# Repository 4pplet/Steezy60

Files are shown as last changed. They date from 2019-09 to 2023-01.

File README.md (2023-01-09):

# Steezy60

Steezy60 is a 60% PCB in two versions: one for SMK gen 2 switches one for ALPS-compatible switches. Compatible with standard tray-mount cases.

## Some features:
- Extensive layout support for use with vintage keycap sets
- QMK
- Simple VIA support (just common layout options)
- USB C
- RGB underglow
- Cherry PCB-stab support for most layout options
- USB horizontal placement is classic GH60, same as GH60, plain60, voyager60 etc.
- JST-connector for daughter board (two different positions, one for bakeneko, one for cases compatible with wilba PCB.)

### SMK:
- Support for MX-mount switch on 6.25u and 7u spacebar position, this to enable use of silenced MX-switch on large spacebars. (no onion chopping spacebar sound)
- Support for some of the weird Alps switch positions for compatibility with SMK Alps mount switches and classic Alps keysets (not for cherry stem SMK switches).

## Availability:
As an option to DIY, I'll try and keep these available for purchase here: https://4pplet.com/ For DIY, the production files are avaliable in releases.

## Altium view of ALPS PCB
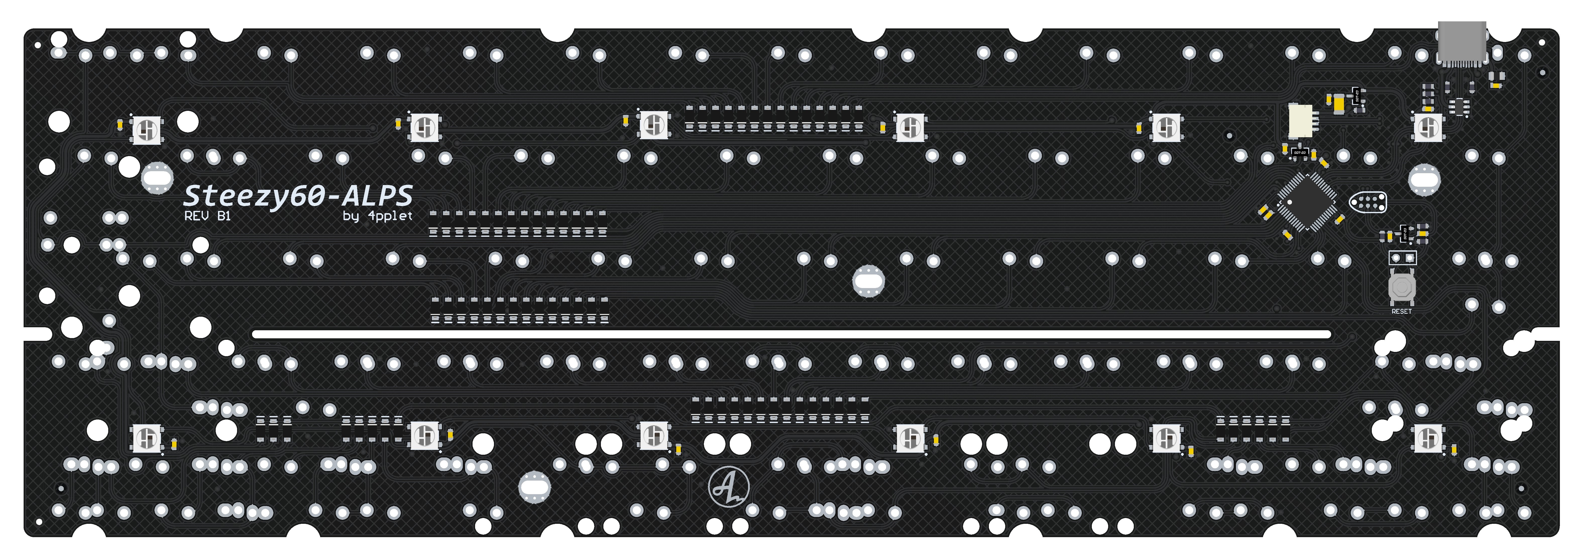
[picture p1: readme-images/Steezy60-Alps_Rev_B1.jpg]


## Altium view of SMK PCB
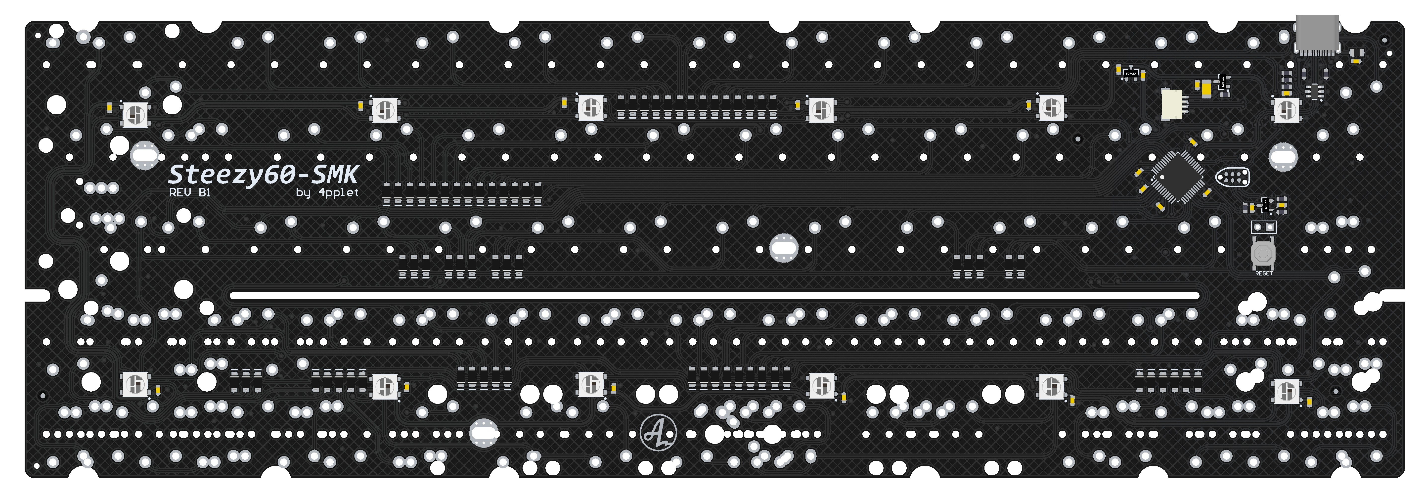
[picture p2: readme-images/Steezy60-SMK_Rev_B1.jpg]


## Layout support:
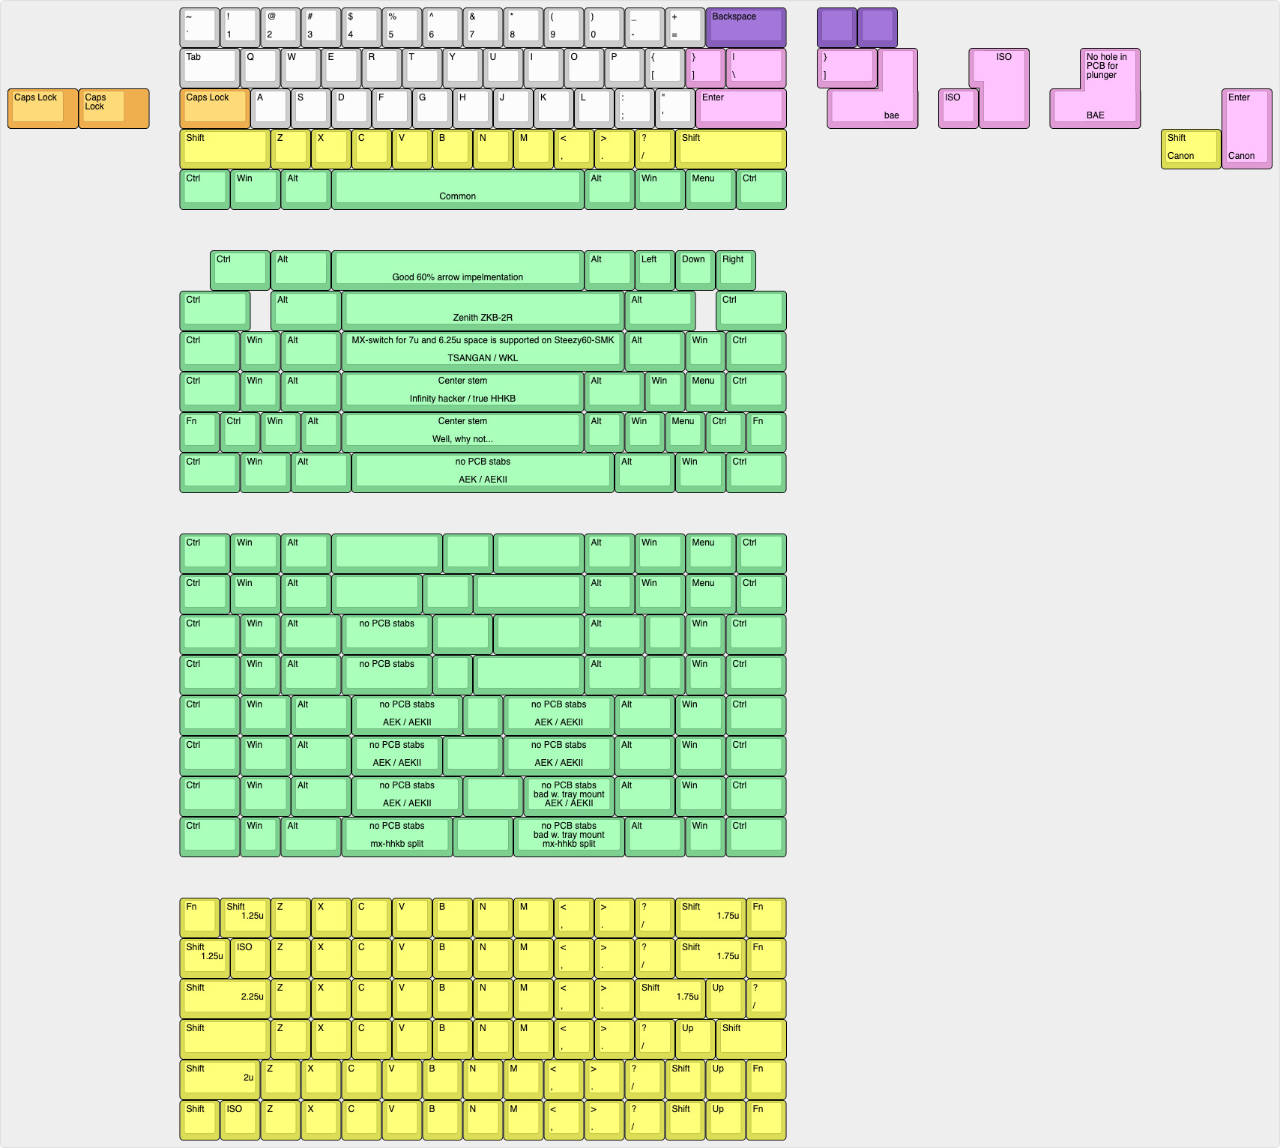
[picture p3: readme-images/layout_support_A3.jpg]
Layout support


## Instructions for manufacturing.

The Project can be assembled in three different configurations:
1. Traditional tray mount with USB-C connector
2. Daughter board connector
In most versions, a "all" configuration is also included, this is not a "one config fits all", it's intended to be used for making your own config.

## For ordering:
The following files are needed for the PCB Fab:
- BOM (contains component specifications)
- Pick and Place (contains component placement data)
- Gerber (contains PCB drawings and drill files)
- (optional) Assembly drawing, for manual assembly

Select the files for the desired configuration. Gerber and Pick and Place files will be the same for all three configurations, BUT!, you need to select the correct BOM for your configuration.

If you want to make a bakeneko compatible PCB, select the bakeneko BOM when ordering PCB's etc.

## For clarity
- Revision: When updating the PCB I bump the revision. The revision is specified with a letter and a number. For big changes, the letter is changed (usually also include code changes), for minor changes, only the number is bumped.
- Version: Version specifies different switch types, PCB's specific to certain cases etc.
- Configuration: Different assembly options for a specific version of steezy60 

## Revisions:

### SMK 
- Rev A1: Initial prototype, issues: had 2 alps footprints left over from other pcb.
- Rev B1: Changed processor to atmega32u2, changed layout support, removed some mounting holes (for chinese cases).
- Rev A2: Rotated left shift stabilizer for better universal plate support, reset revision designator to A (old A-revision does not exist anymore), to match Steezy60-Alps. Removed PCB name and logo on top, removed flash command from silk.
- Rev A3: Added support for Canon Spherical Keycaps, improved routing, added support for rubber-band mouting.
- Rev A4: Moved daughter board connector to allign with other projects.
- Rev A5: Moved daughter board a bit to fit better in bakeneko cases, Added cutout for bakeneko V3 (untested), Added assembly option for PCB to fit in wilba cases (untested).
- Rev B1: Changing CPU to ARM, removing wilba PCB-support

### ALPS
- Rev A1: Initial prototype based on SMK-version.
- Rev A2: Rotated left shift stabilizer for better universal plate support, removed PCB name and logo on top, removed flash command from silk.
- Rev A3: Added support for Canon Spherical Keycaps, improved routing, added support for rubber-band mouting.
- Rev A4: Moved daughter board connector to allign with other projects.
- Rev A5: Moved daughter board a bit to fit better in bakeneko cases, Added cutout for bakeneko V3 (untested), Added assembly option for PCB to fit in wilba cases (untested).
- Rev B1: Changing CPU to ARM, removing wilba PCB-support

<a href='https://ko-fi.com/4pplet' target='_blank'>Buy Me a Coffee at ko-fi.com

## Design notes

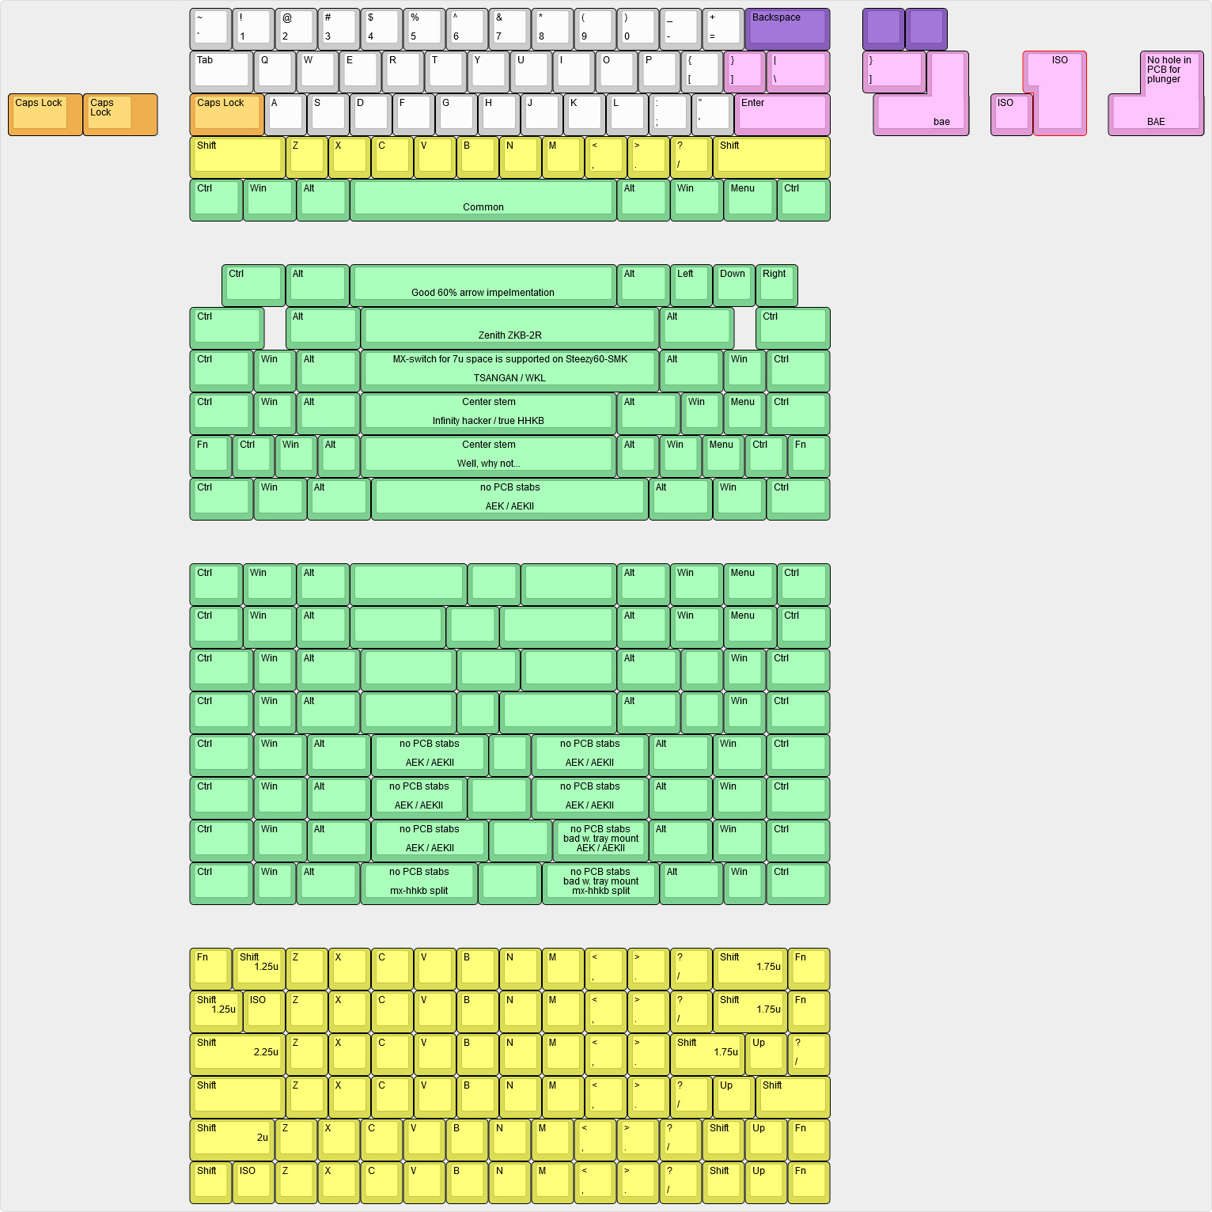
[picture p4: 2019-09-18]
readme-images/layout_support_A2.jpg

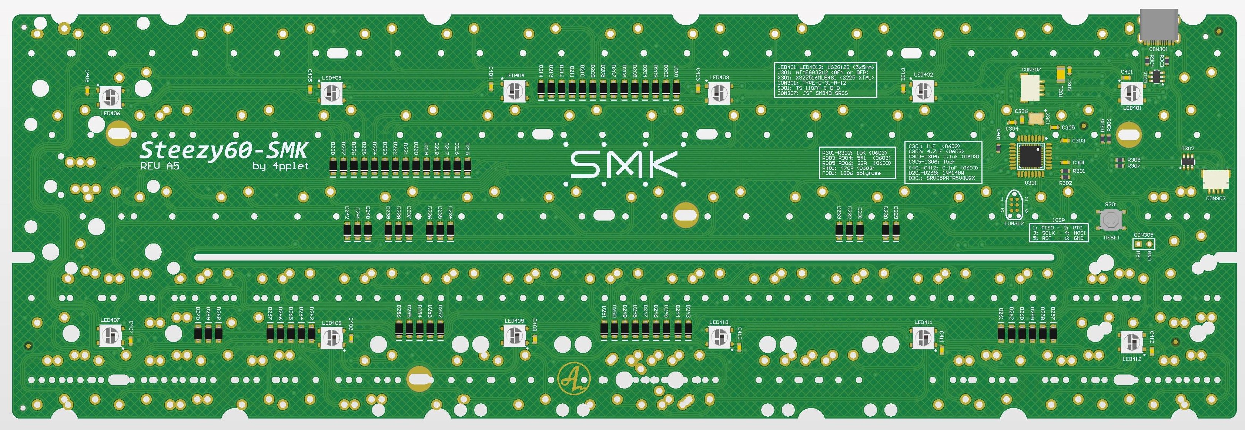
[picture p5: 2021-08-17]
readme-images/Steezy60-SMK_Rev_A5.jpg

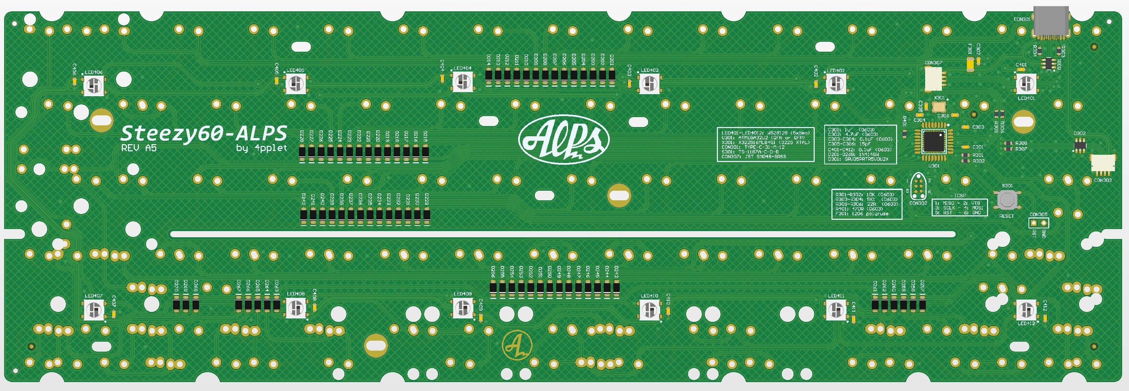
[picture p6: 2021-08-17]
readme-images/Steezy60-Alps_Rev_A5.jpg

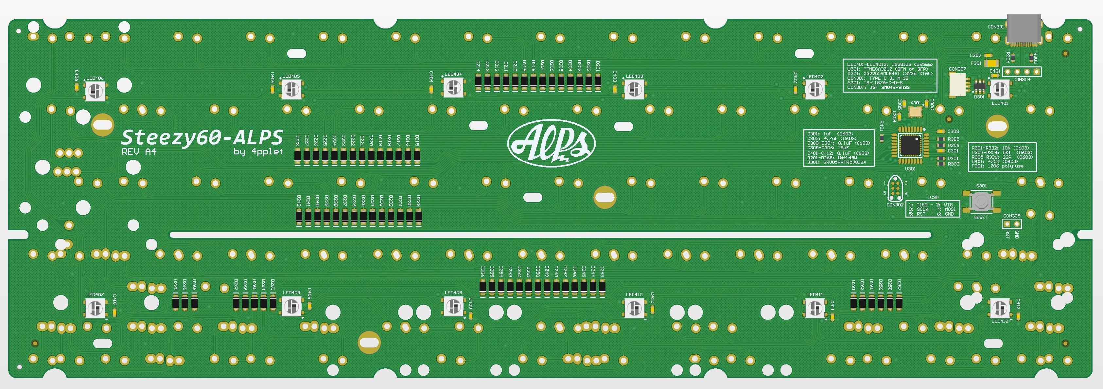
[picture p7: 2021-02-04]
readme-images/Steezy60-Alps_Rev_A4.jpg

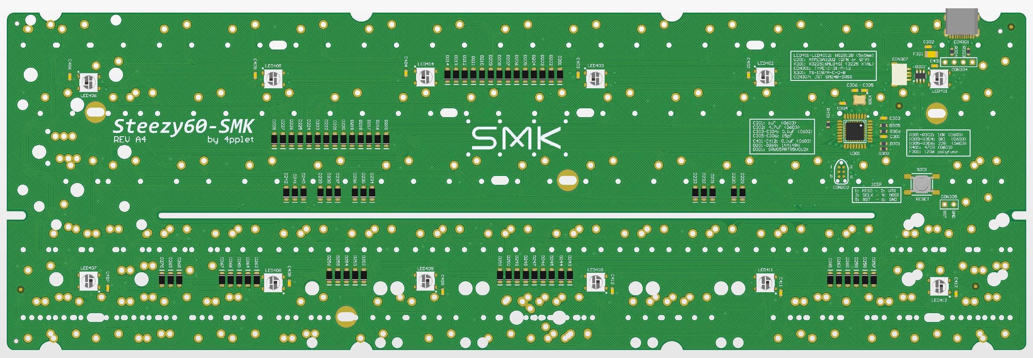
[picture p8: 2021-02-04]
readme-images/Steezy60-SMK_Rev_A4.jpg

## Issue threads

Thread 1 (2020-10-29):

smk rev a3 led407

anthonysymak, 2020-10-29:
led not work due to GND not connected.   attached photo showing remedy.
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

4pplet, 2020-10-29:
Thanks for showing interest in the project! :)

Did you use the files from the release? My guess is that your PCB has a faulty VIA shown below.
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

I have made PCB's using the files in the release A3 and have no issues with LED407
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

anthonysymak, 2020-10-29:
Hi, thanks for reply, I do use the release.  but not a big issue.  Just
report to the property owner.

Thanks again.

Anthony

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

anthonysymak, 2020-10-29:
for your informtion, I downloaded the release on Oct 8.

Thank you

4pplet, 2020-11-01:
Thanks for reporting it, hope you are happy with the board! :) Closing the issue

Closed 2020-11-01.

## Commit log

2019-05-24 initial commit
    initial commit, lots of error checking to do
    [1_top.SchDoc, 2_matrix.SchDoc, 3_mcu.SchDoc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]
2019-06-06 First draft
    First draft of cherry and mx compatibility.
    [1_top.SchDoc, 2_matrix.SchDoc, 3_mcu.SchDoc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]
2019-06-06 made schematic and layout in sync
    made schematic and layout in sync before starting to make changes, also removed room.
    [2_matrix.SchDoc, PcbLib1.PcbLib]
2019-06-11 wtf
    wtf
    [2_matrix.SchDoc, 3_mcu.SchDoc, 4_periferals.SchDoc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]
2019-06-20 Alps_SMK_60+5
    PCB compatible with smk and alps switches that can be used for both 60 and 65%
    [1_top.SchDoc, 3_mcu.SchDoc, PcbLib1.PcbLib]
2019-06-26 Files ready for prototype run "Proto A1"
    [1_top.SchDoc, 2_matrix.SchDoc, 3_mcu.SchDoc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]
2019-06-27 rename project file.
    [Steezy60.PrjPcb]
2019-07-08 changed two incorrect footprints and modified buzzer
    Two footprints was still alps-mount, increased pads for buzzer for hand soldering
    [2_matrix.SchDoc, 3_mcu.SchDoc, PcbLib1.PcbLib]
2019-07-09 Added layout support
    added 5x 1u modifiers on left side bottom row and a offset row4 (2u/1u LShift) "abomination support"
    [2_matrix.SchDoc, PcbLib1.PcbLib]
2019-07-10 corrected offset row4
    corrected offset row4, was too small offset
    [3_mcu.SchDoc, PcbLib1.PcbLib]
2019-07-13 Major changes
    Major changes, changed processor to atmega32u2, removed backlight on PCB (can be added on header)
    [1_top.SchDoc, 2_matrix.SchDoc, 3_mcu.SchDoc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]
2019-07-13 Removed some layout support
    Removed some layout support and changed some slots to just holes.
    [2_matrix.SchDoc]
2019-08-21 fixes, added designator text
    fixes, added designator text
    [1_top.SchDoc, 2_matrix.SchDoc, 3_mcu.SchDoc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]
2019-08-30 Added mx support for 6.25u space and more
    Added mx support for 6.25u space, cleaned up schematic a bit
    [2_matrix.SchDoc, 3_mcu.SchDoc, 4_periferals.SchDoc]
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2019-09-05 Files for B1 run almost done, error checking left
    Files for B1 run almost done, error checking left
    [2_matrix.SchDoc, 3_mcu.SchDoc, 4_periferals.SchDoc]
2019-09-10 DRC checked and outjob updated
    DRC checked and outjob updated
    [3_mcu.SchDoc]
2019-09-18 Updated S269-pa to possibly prevent issue with screw in stabs
    Updated S269-pa to possibly prevent issue with screw in stabs. Updated readme
2019-09-29 updated silkscreen, added atmega QFN support
    updated silkscreen, added atmega QFN support, added ICSP-header on top
    [3_mcu.SchDoc]
2019-10-07 Fixed issue with old footprint loaded to new design
    Fixed issue with old footprint loaded to new design. Removed two local feducials and loaded new feducial footprints.
    [4_periferals.SchDoc]
2019-10-11 minor tweaks
    minor tweaks
    [4_periferals.SchDoc]
2019-10-12 removed unused files
    removed unused files
    [3_mcu.SchDoc, 4_periferals.SchDoc, PcbLib1.PcbLib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]
2019-11-19 Added LCSC part numbers
    Added LCSC part numbers
    [1_top.SchDoc, 2_matrix.SchDoc, 3_mcu.SchDoc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]
2019-11-19 added pinout for connectors on bottom silk
    added pinout for connectors on bottom silk
2019-11-23 Updated diode numbering and fiducial footprint
    Updated diode numbering and fiducial footprint
    [2_matrix.SchDoc, 4_periferals.SchDoc]
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2019-11-30 Release B2
    Release B2
    [Steezy60SMK.PrjPcb]
2019-11-30 Updated project file
    Updated project file
    [Steezy60SMK.PrjPcb]
2019-12-13 Started to update pinout for underglow leds
    Started to update pinout for underglow leds
    [4_periferals.SchDoc]
2020-01-14 Updated underglow LED with LCSC part
    Updated underglow LED with LCSC part
    [4_periferals.SchDoc]
2020-01-16 Started to add JST connector for USB
    Started to add JST connector for USB
    [3_mcu.SchDoc]
2020-01-17 Added LCSC numbers
    Added LCSC numbers
    [3_mcu.SchDoc]
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2020-01-31 Combined SMK and ALPS repo to one Steezy60-repo
    Combined SMK and ALPS repo to one Steezy60-repo
    [1_top.SchDoc, 2_matrix.SchDoc, 3_mcu.SchDoc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]
2020-01-31 Fixed keeb-lib path
    Fixed keeb-lib path, changed size on headers in readme
    [Steezy60ALPS.PrjPcb, Steezy60SMK.PrjPcb]
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2020-02-05 made schematic prettier
    made schematic prettier
    [3_mcu.SchDoc]
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2020-02-07 fixed silk, restored usb gnd vias, made pads around all mounting holes
    fixed silk, restored usb gnd vias, made pads around all mounting holes
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2020-03-08 Updated reset-button footprint and reset revision to A1 for combined project
    Updated reset-button footprint and reset revision to A1 for combined project
    [3_mcu.SchDoc]
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2020-03-30 removed pad-opening in top-solder for switches, moved usb-connector out a bit
    removed pad-opening in top-solder for switches, moved usb-connector out a bit
    [2_matrix.SchDoc, 3_mcu.SchDoc]
2020-04-01 updated schematic without issues where names were missing
    updated schematic without issues where names were missing
2020-04-01 DRC check ok on alps PCB, routing decent
    DRC check ok on alps PCB, routing decent
    [Steezy60ALPS.PrjPcb]
2020-04-01 DRC ok on SMK-version, routing decent
    DRC ok on SMK-version, routing decent
    [Steezy60SMK.PrjPcb]
2020-04-02 Added tooling holes and modified bom and pick and place to JLC spec
    Added tooling holes and modified bom and pick and place to JLC spec
    [2_matrix.SchDoc, 3_mcu.SchDoc, 4_periferals.SchDoc]
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2020-04-23 restored flex cut, but 1.5mm
2020-04-23 updated for JLC assembly
    updated for JLC assembly
    [2_matrix.SchDoc, 3_mcu.SchDoc, 4_periferals.SchDoc]
2020-06-07 Started revision A3, added canon spherical support and THT reset button under space
    Started revision A3, added canon spherical support and THT reset button under space
    [2_matrix.SchDoc, Steezy60ALPS.PrjPcb, Steezy60SMK.PrjPcb]
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2020-09-11 updating to new ESD-chip and diodes
    [2_matrix.SchDoc, 3_mcu.SchDoc]
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2020-09-18 curving traces
    [Steezy60ALPS.PrjPcb, Steezy60SMK.PrjPcb]
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2020-09-28 started replacing diodes
    [2_matrix.SchDoc]
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2020-09-30 updated component parameters
    [2_matrix.SchDoc, 3_mcu.SchDoc, 4_periferals.SchDoc]
2020-09-30 DRC OK
    [3_mcu.SchDoc, Steezy60ALPS.PrjPcb, Steezy60SMK.PrjPcb]
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2020-10-04 simplified BOM, need to fix Alps-silkscreen
    [3_mcu.SchDoc]
2020-10-04 fixed BOM on silkscreen
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2021-01-08 schematic clean up
    [3_mcu.SchDoc, 4_periferals.SchDoc]
2021-01-08 cleaning up schematic
    [1_top.SchDoc, 2_matrix.SchDoc, 3_mcu.SchDoc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]
2021-01-08 minor schematic text update
    [1_top.SchDoc, 2_matrix.SchDoc, 3_mcu.SchDoc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]
2021-01-15 cont on rev a4
    [2_matrix.SchDoc, 3_mcu.SchDoc, Steezy60ALPS.PrjPcb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]
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2021-05-29 implemented, no DRC done
    [2_matrix.SchDoc, 3_mcu.SchDoc]
2021-08-17 added variants
    [Steezy60ALPS.PrjPcb, Steezy60SMK.PrjPcb]
2025-02-05 Adding revision B2
    [3_mcu.SchDoc, 4_periferals.SchDoc, Steezy60ALPS.PcbDoc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]
